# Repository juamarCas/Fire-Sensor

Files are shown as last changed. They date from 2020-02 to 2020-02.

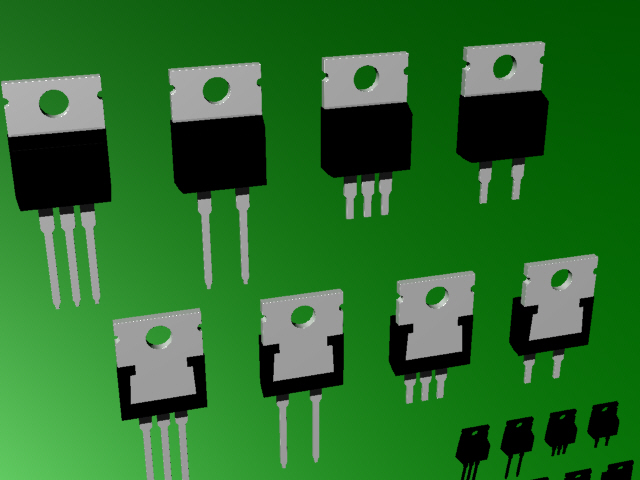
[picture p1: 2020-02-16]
T220/TO-220_4.jpg

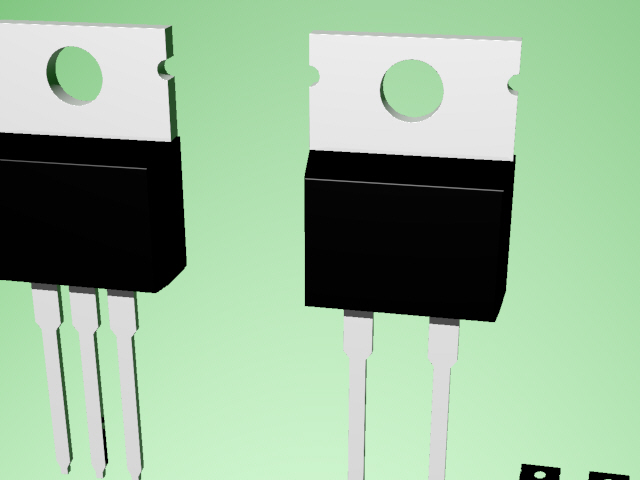
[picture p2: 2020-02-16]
T220/TO-220_3.jpg

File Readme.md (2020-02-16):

# Fire sensor network
This project conssists on a prototype of a Wireless Sensor Network(WSN) for fire detection.
The design is made in Ki-Cad
## Sensor node
It uses the Atmega328 (Arduino one).
connector J1 you can connect a battery to measure the energy left.

### Code
the code for each sensor is in  _Transmmiter.ino_ 
when you configure the channels you have to know that it has to be a
number in octal format like this:
```
int this_node = 01; 
```

## Base node
It uses NodeMCU with the ESP8266, 

### Code 
the code is _BaseNode2.ino_
also use octal form for channels

## Libraries
-We used the nrf24L01 library to communicate each node, you can find the library here [GitHub Pages](https://github.com/nRF24/RF24)

-To make a network we used nrf24l01 network library [GitHub Pages](https://github.com/nRF24/RF24Network)

-To meassure temperature and humidity we used the DTH22 library 
[GitHub Pages](https://github.com/adafruit/DHT-sensor-library)

-To send data to the server we used ArduinoJson [ArduinoJson] (https://arduinojson.org/)

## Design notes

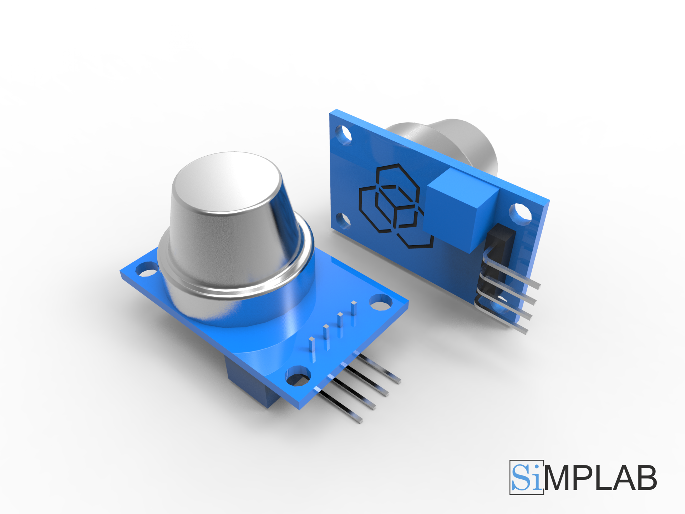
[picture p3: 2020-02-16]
MQ2/Датчик газа MQ2 (дым).png

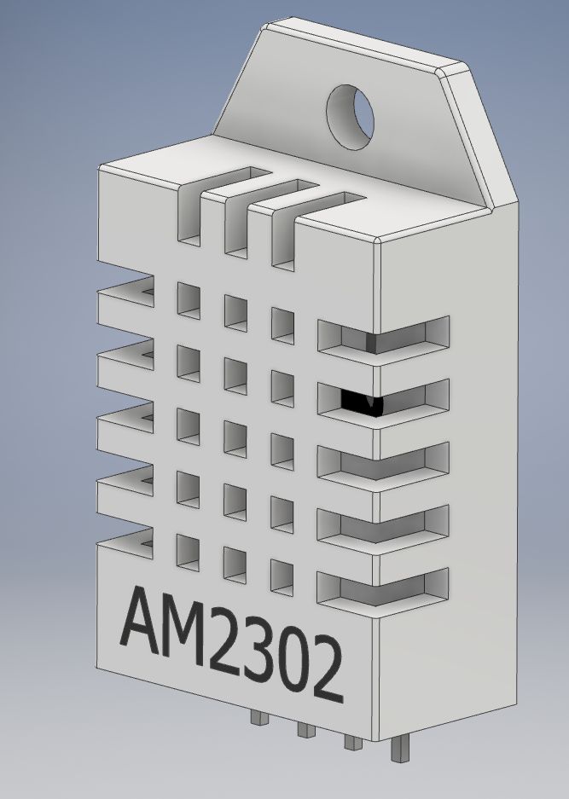
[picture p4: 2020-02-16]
DHT22/Image.jpg

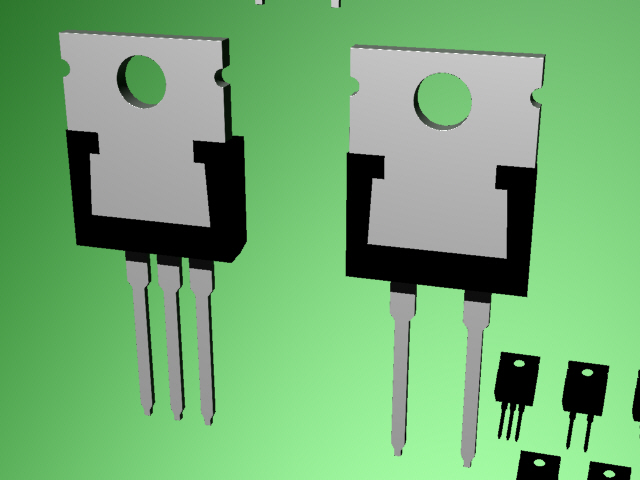
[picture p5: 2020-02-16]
T220/TO-220_2.jpg

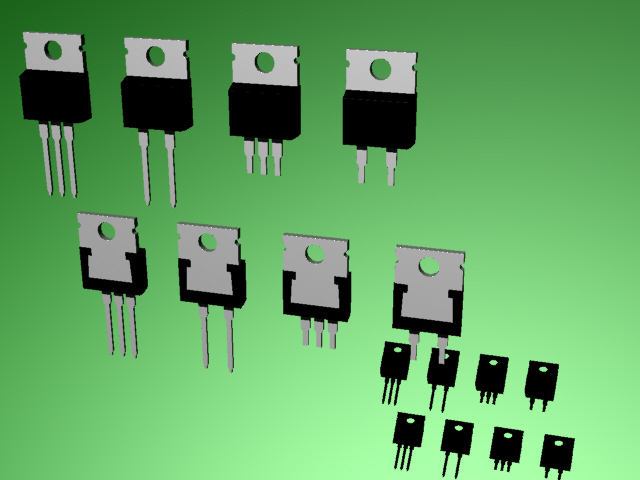
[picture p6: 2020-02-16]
T220/TO-220_1.jpg

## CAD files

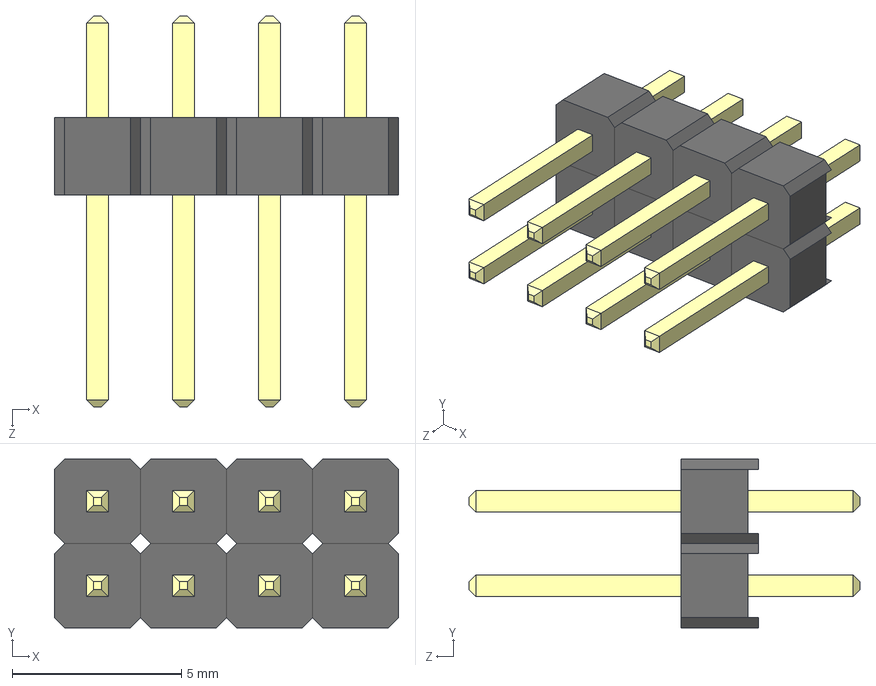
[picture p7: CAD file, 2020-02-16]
Antenas/nrd24l01/User Library-2_54mm Male Header (4x2).STEP
10.2 x 4.98 x 11.5 mm
User Library-Header_Male_4Pin_PinArray x 2
User Library-Header_Male_4Pin_BodyArray x 2

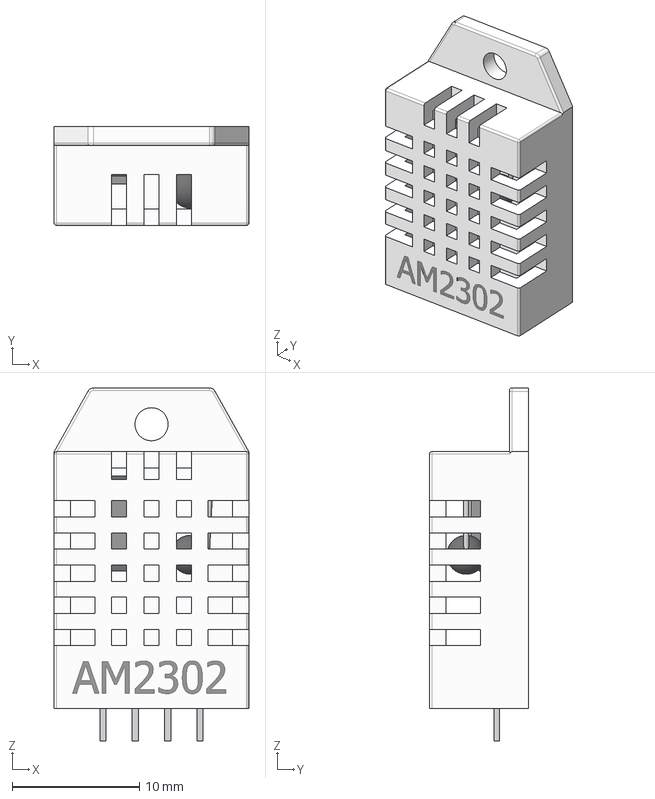
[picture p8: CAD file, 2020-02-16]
DHT22/DHT22.stp
15.3 x 7.80 x 27.7 mm

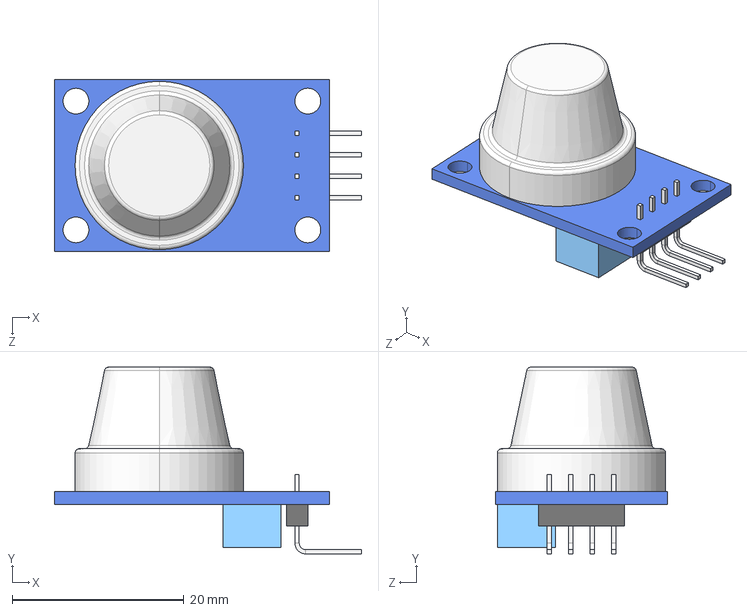
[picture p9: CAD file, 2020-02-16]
MQ2/MQ2.STEP
35.8 x 21.8 x 20.0 mm

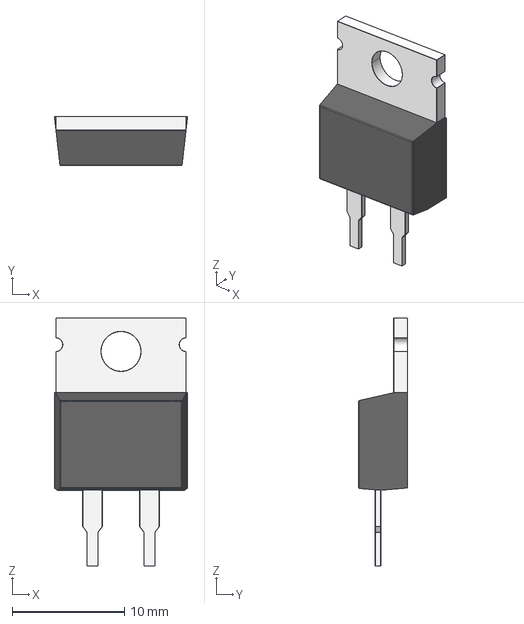
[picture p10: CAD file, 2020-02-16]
T220/TO-220 2pins short V1.stp
11.9 x 4.40 x 22.1 mm

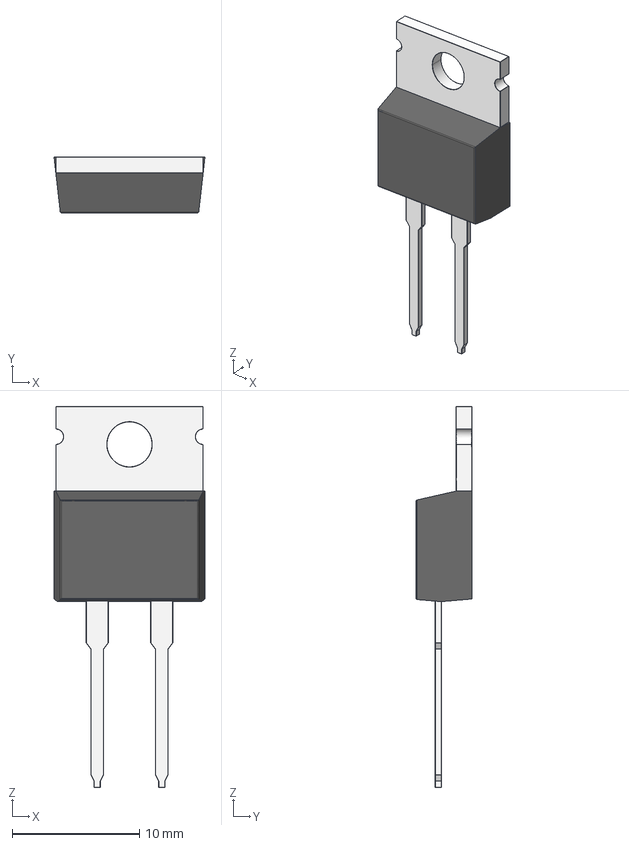
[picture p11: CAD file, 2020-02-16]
T220/TO-220 2pins long V1.stp
11.9 x 4.40 x 30.0 mm

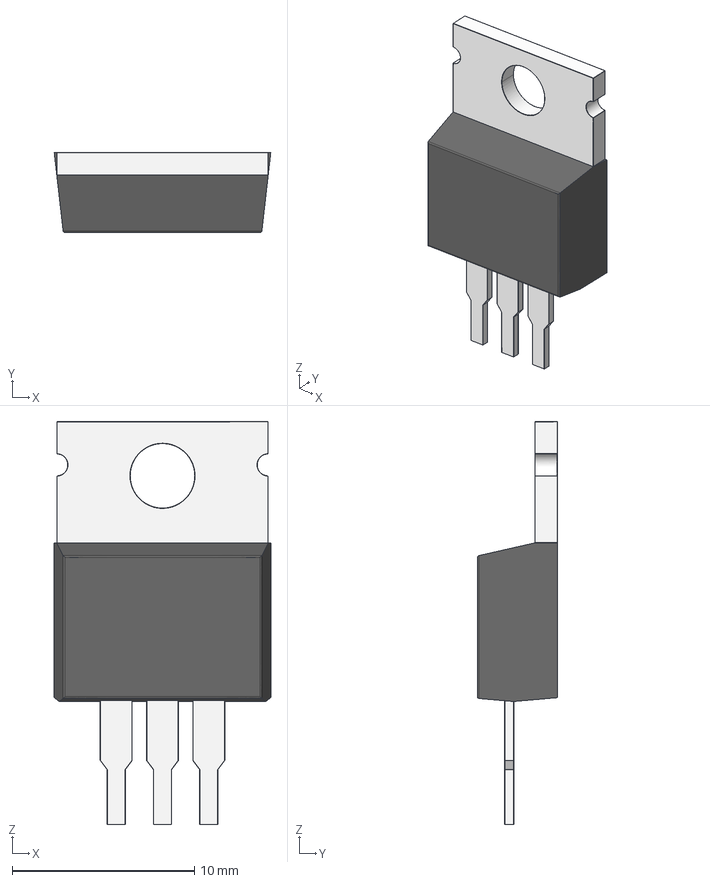
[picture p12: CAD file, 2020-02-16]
T220/TO-220 3pins short V1.stp
11.9 x 4.40 x 22.1 mm

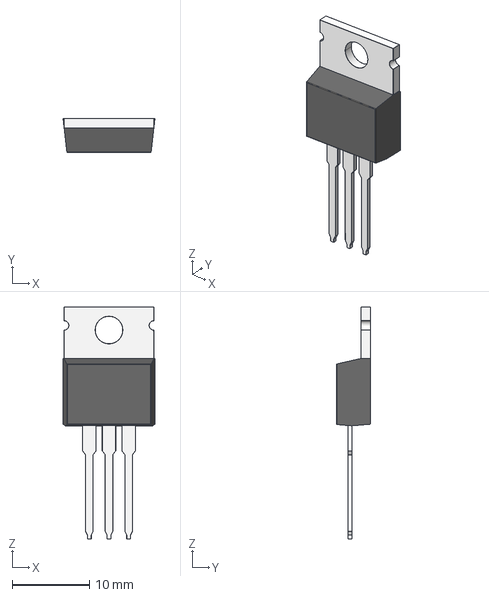
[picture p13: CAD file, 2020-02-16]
T220/TO-220 3pins long V1.stp
11.9 x 4.40 x 30.0 mm

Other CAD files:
MQ2/Датчик газа MQ2 (дым).x_b
T220/TO-220 2pins long V1.igs
T220/TO-220 2pins short V1.igs
T220/TO-220 3pins long V1.igs
T220/TO-220 3pins short V1.igs

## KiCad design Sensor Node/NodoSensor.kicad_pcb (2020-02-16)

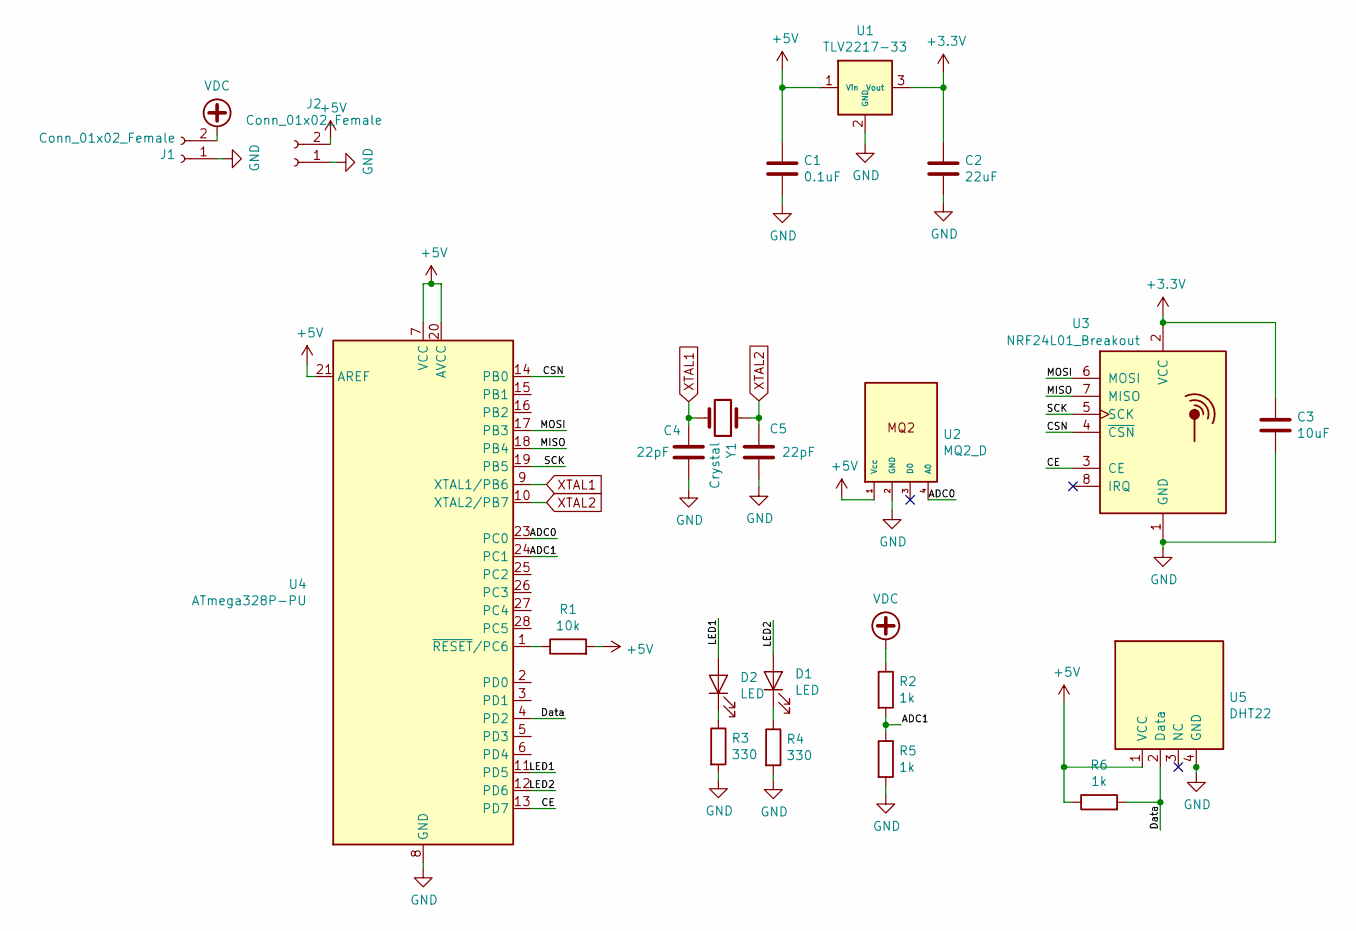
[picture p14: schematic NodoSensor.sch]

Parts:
C1: 0.1uF; CP_Radial_D5.0mm_P2.50mm
C2: 22uF; CP_Radial_D5.0mm_P2.50mm
C3: 10uF; CP_Radial_D5.0mm_P2.50mm
C4, C5: 22pF; C_Disc_D3.0mm_W2.0mm_P2.50mm
D1, D2: LED; LED_D3.0mm
J1, J2: Conn_01x02_Female; PinHeader_1x02_P2.54mm_Vertical
R1: 10k; R_Axial_DIN0309_L9.0mm_D3.2mm_P12.70mm_Horizontal
R2: 1k; R_Axial_DIN0309_L9.0mm_D3.2mm_P12.70mm_Horizontal
R3, R4: 330; R_Axial_DIN0207_L6.3mm_D2.5mm_P10.16mm_Horizontal
R5, R6: 1k; R_Axial_DIN0207_L6.3mm_D2.5mm_P10.16mm_Horizontal
U1: TLV2217-33; SIPAK_Vertical
U2: MQ2_D
U3: NRF24L01_Breakout; nRF24L01_Breakout
U4: ATmega328P-PU; DIP-28_W7.62mm
U5: DHT22
Y1: Crystal; Crystal_HC49-U_Vertical

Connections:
+3V3: C2.1, C3.1, U1.3 (Vout), U3.2 (VCC)
+5V: C1.1, J2.2, R1.2, R6.1, U1.1 (Vin), U2.1 (Vcc), U4.7 (VCC), U4.20 (AVCC), U4.21 (AREF), U5.1 (VCC)
/ADC0: U2.4 (A0), U4.23 (PC0)
/ADC1: R2.2, R5.1, U4.24 (PC1)
/CE: U3.3 (CE), U4.13 (PD7)
/CSN: U3.4 (~CSN), U4.14 (PB0)
/Data: R6.2, U4.4 (PD2), U5.2 (Data)
/LED1: D2.2 (A), U4.11 (PD5)
/LED2: D1.2 (A), U4.12 (PD6)
/MISO: U3.7 (MISO), U4.18 (PB4)
/MOSI: U3.6 (MOSI), U4.17 (PB3)
/SCK: U3.5 (SCK), U4.19 (PB5)
GND: C1.2, C2.2, C3.2, C4.2, C5.2, J1.1, J2.1, R3.2, R4.2, R5.2, U1.2 (GND), U2.2 (GND), U3.1 (GND), U4.8 (GND), U4.22 (GND), U5.4 (GND)
unnamed: D1.1 (K), R4.1
unnamed: D2.1 (K), R3.1
unnamed: R1.1, U4.1 (~RESET~/PC6)
VDC: J1.2, R2.1
XTAL1: C4.1, U4.9 (XTAL1/PB6), Y1.2
XTAL2: C5.1, U4.10 (XTAL2/PB7), Y1.1

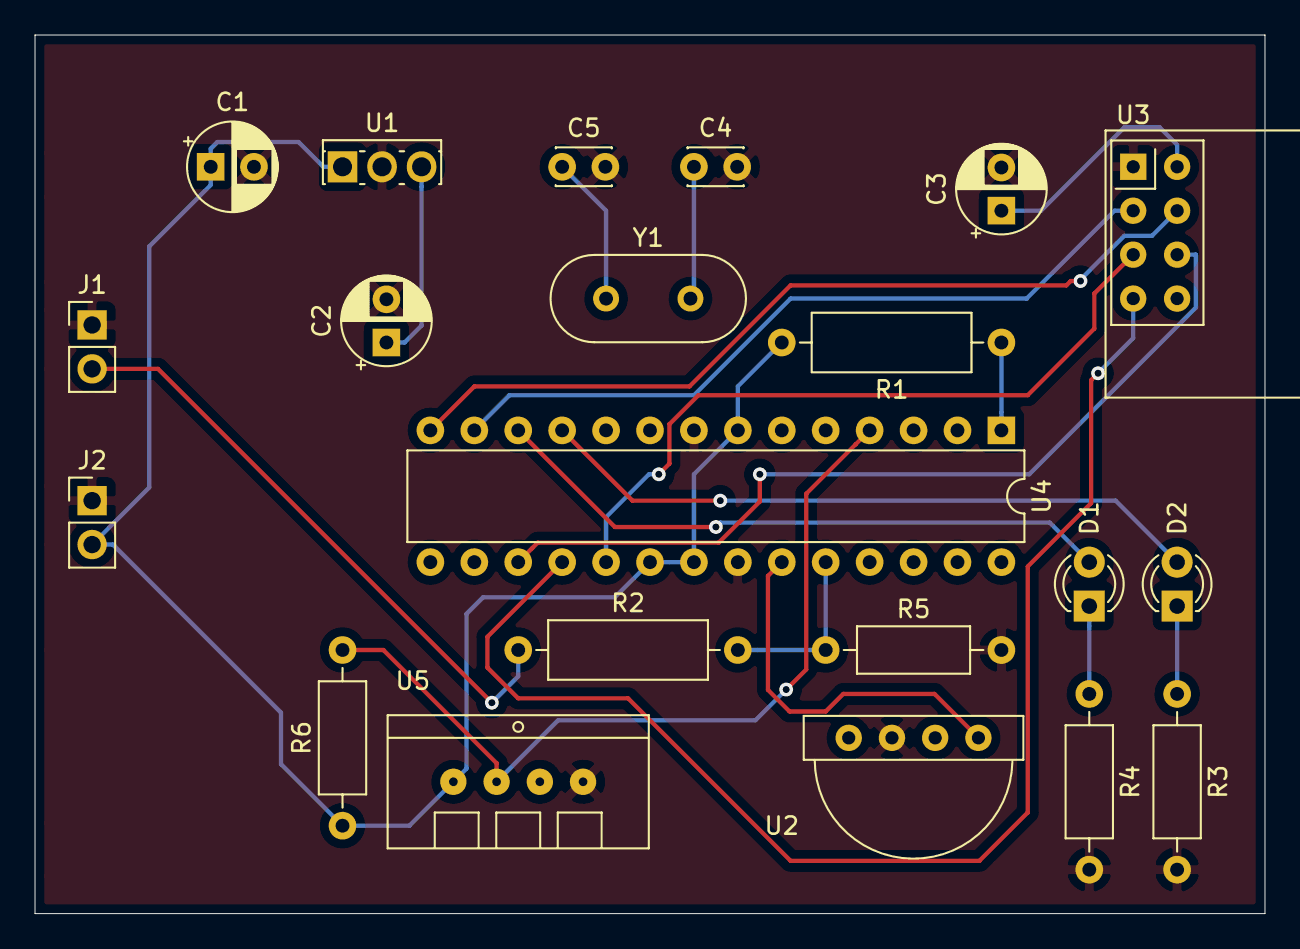
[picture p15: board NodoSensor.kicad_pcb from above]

Board: 2 copper layers, 71.1 x 50.8 mm, 21 parts (0 on the bottom side), 19 nets.

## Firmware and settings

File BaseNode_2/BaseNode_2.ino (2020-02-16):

#include <ESP8266WiFi.h>
#include <ESP8266HTTPClient.h>

#include <ArduinoJson.h>
#include <RF24Network.h>
#include <RF24.h>
#include <SPI.h>


// el espacio necesitado en el nodo mcu para el json es 148 mínimo
//para AVR es 100
RF24 radio(2, 15);               // nRF24L01(+) radio attached using Getting Started board

RF24Network network(radio);      // Network uses that radio
//agregar más nodos en caso de tener más de la siguiente manera:
// const uint16_t other_node(num) = xx; // xx es un número en forma octal diferente a los anteriores
const uint16_t this_node = 00;    // Address of our node in Octal format ( 04,031, etc)
const uint16_t other_node1 = 01;
const uint16_t other_node2 = 02;// Address of the other node in Octal format
const uint16_t other_node3 = 03;
const uint16_t other_node4 = 04;
const uint16_t other_node5 = 05;

struct payload_t {                  // Structure of our payload
  float temperature;
  float smoke;
  float humidity;
  float batteryLevel;
  bool state; // falso = normal, verdadero = alerta
  char text[32];
};

int interval = 10000; //10 segundos por defecto

void setup(void)
{
  Serial.begin(9600);
  Serial.println("RF24Network/examples/helloworld_rx/");

  SPI.begin();
  radio.begin();
  radio.setPALevel(RF24_PA_MAX);
  network.begin(/*channel*/ 90, /*node address*/ this_node);

  //Serial connection
  WiFi.begin("", "");   //WiFi connection

  while (WiFi.status() != WL_CONNECTED) {  //Wait for the WiFI connection completion

    delay(500);
    Serial.println("Waiting for connection");

  }
}

void loop(void) {

  // Check the network regularly

  network.update();
  while ( network.available() ) {     // Is there anything ready for us?

    if (WiFi.status() == WL_CONNECTED) {
      const size_t capacity = JSON_OBJECT_SIZE(6);
      DynamicJsonBuffer jsonBuffer(capacity);
      JsonObject& root = jsonBuffer.createObject();

      payload_t payload;
      RF24NetworkHeader header;
      
      /* RF24NetworkHeader header4(other_node4);
        RF24NetworkHeader header5(other_node5);
        RF24NetworkHeader header6(other_node6);
        RF24NetworkHeader header7(other_node7);*/
      network.read(header, &payload, sizeof(payload));
      if (header.from_node == 01) {
        root["id"] = payload.text;
        root["temperature"] = payload.temperature;
        root["humidity"] = payload.humidity;
        root["smoke"] = payload.smoke;
        root["battery"] = payload.batteryLevel;
        root["state"] = payload.state;
      }
      if (header.from_node == 02) {      
        root["id"] = payload.text;
        root["temperature"] = payload.temperature;
        root["humidity"] = payload.humidity;
        root["smoke"] = payload.smoke;
        root["battery"] = payload.batteryLevel;
        root["state"] = payload.state;
      }
      if (header.from_node == 03) {
       
        root["id"] = payload.text;
        root["temperature"] = payload.temperature;
        root["humidity"] = payload.humidity;
        root["smoke"] = payload.smoke;
        root["battery"] = payload.batteryLevel;
        root["state"] = payload.state;
      }
      
      if (header.from_node == 04) {
       
        root["id"] = payload.text;
        root["temperature"] = payload.temperature;
        root["humidity"] = payload.humidity;
        root["smoke"] = payload.smoke;
        root["battery"] = payload.batteryLevel;
        root["state"] = payload.state;
      }
      
      if (header.from_node == 05) {
       
        root["id"] = payload.text;
        root["temperature"] = payload.temperature;
        root["humidity"] = payload.humidity;
        root["smoke"] = payload.smoke;
        root["battery"] = payload.batteryLevel;
        root["state"] = payload.state;
      }

      if (header.from_node == 012) {
       
        root["id"] = payload.text;
        root["temperature"] = payload.temperature;
        root["humidity"] = payload.humidity;
        root["smoke"] = payload.smoke;
        root["battery"] = payload.batteryLevel;
        root["state"] = payload.state;
      }
      

      if(payload.state){
        interval = 1000; //3 segundos
      }
    
      char JSONmessageBuffer[500];
      root.prettyPrintTo(JSONmessageBuffer, sizeof(JSONmessageBuffer));
      Serial.println(JSONmessageBuffer);

      HTTPClient http;    //Declare object of class HTTPClient
      http.begin("http://ddb461bb.ngrok.io/api/status/post/");      //Specify request destination
      http.addHeader("Content-Type", "application/json");  //Specify content-type header
      int httpCode = http.POST(JSONmessageBuffer);   //Send the request
      String payloads = http.getString();                                        //Get the response payload
      Serial.println(httpCode);   //Print HTTP return code
      Serial.println(payloads);    //Print request response payload
      http.end();  //Close connection
      Serial.println();



      for(int i = 0; i < interval; i++){
        delay(1);
      }
    } else {
      Serial.println("Error in WiFi connection");
    }
  }
}

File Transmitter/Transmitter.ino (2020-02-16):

#include <RF24Network.h>
#include <RF24.h>
#include <SPI.h>
#include "DHT.h"

#define dhtpin 2
#define DHTTYPE DHT22

#define smokePin A0
#define readBattPin A1

#define maxTemp 36
#define minHum 30
#define maxSmk 125
#define minBatt 291

#define batteryLevelPin 5
#define sentConfirmationPin 4

DHT dht(dhtpin, DHTTYPE);

RF24 radio(7, 8);                   // nRF24L01(+) radio attached using Getting Started board

RF24Network network(radio);          // Network uses that radio

const uint16_t this_node = 012;        // Address of our node in Octal format
const uint16_t other_node = 00;       // Address of the other node in Octal format

const unsigned long interval = 1000; //ms  // How often to send 'hello world to the other unit

unsigned long last_sent;             // When did we last send?
unsigned long packets_sent;          // How many have we sent already


struct payload_t {                  // Structure of our payload
  float temperature;
  float smoke;
  float humidity;
  float bat;
  bool state;
  char text[32];
};

void setup(void)
{
  Serial.begin(9600);
  Serial.println("RF24Network/examples/helloworld_tx/");
  pinMode(batteryLevelPin, OUTPUT);
  pinMode(sentConfirmationPin, OUTPUT);
  SPI.begin();
  dht.begin();
  radio.begin();
  radio.setPALevel(RF24_PA_MAX);


  network.begin(/*channel*/ 90, /*node address*/ this_node);
}

void loop() {
  float temp = dht.readTemperature();
  float hum = dht.readHumidity();
  float smk = analogRead(smokePin);
  float battery = analogRead(readBattPin);
  bool states = false;
  network.update();                          // Check the network regularly

  if((smk >= maxSmk) || (temp >= maxTemp && hum < minHum) || (temp >= (maxTemp + 4))){
    states = true;
  }else{
    states = false; 
  }

  if(battery <= minBatt){
    digitalWrite(batteryLevelPin, HIGH); 
  }else{
    digitalWrite(batteryLevelPin, LOW);
  }
  

  unsigned long now = millis();              // If it's time to send a message, send it!
  if ( now - last_sent >= interval  )
  {
    last_sent = now;
    payload_t payload = { temp, hum, smk, battery, states, "1012"};
    RF24NetworkHeader header(/*to node*/ other_node);
    bool ok = network.write(header, &payload, sizeof(payload));
    if (ok) {
      digitalWrite(sentConfirmationPin, HIGH);
    }
    else {
      digitalWrite(sentConfirmationPin, LOW);
    }
  }
}
